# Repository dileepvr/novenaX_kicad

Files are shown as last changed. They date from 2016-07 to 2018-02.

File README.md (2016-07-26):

These are kicad schematics and design files for PCBs used in the
Novena-X project, which aims to build a laptop around the Novena
motherboard released by Kosagi. These design files are being released
(as of this writing on the 30th of April, 2016) under the CERN Open
Hardware License v1.2 (see file LICENSE.txt for text of the license).
All future versions of the CERN Open Hardware License automatically
apply.

For more information about the Novena motherboard, visit: http://www.kosagi.com/w/index.php?title=Novena_Main_Page

For more information about Project Novena-X, visit: http://rightshift.info and refer to the posts titled "Project Novena-X"

The PCB is split into three circuits. One of them is meant to
interface between the Novena front-panel FFC cable and a Dell 0WX4JF
backlit keyboard. It also consists of LEDs driven by six pins from the
FPGA onboard the Novena, as well as buttons for power, reset, and
bluetooth association. The board houses an ATMEGA32u4 microcontroller.

A second circuit merely hosts a pushbutton meant to detect when the case is open/closed.

The third circuit communicates through specific pins on Novena's LVDS
panel FFC cable, and houses two ATMEGA32u4 microcontrollers, as well
as a USB hub (TUSB2046BVFR). This circuit interfaces with an
NHD-044DAZ-FL-YBW 40x4 character LCD screen from New Haven displays,
an e-ink panel arduino shield called ePaper v2 by Seeedstudio, a USB
camera, an nRF24L01+ radio module from Nordic, as well as i2c chips
such as the BME280 weather monitor, the ATAE5132A encrypted EEPROM,
and a AT97SC3205T TPM chip from Atmel.

- Dileep V. Reddy

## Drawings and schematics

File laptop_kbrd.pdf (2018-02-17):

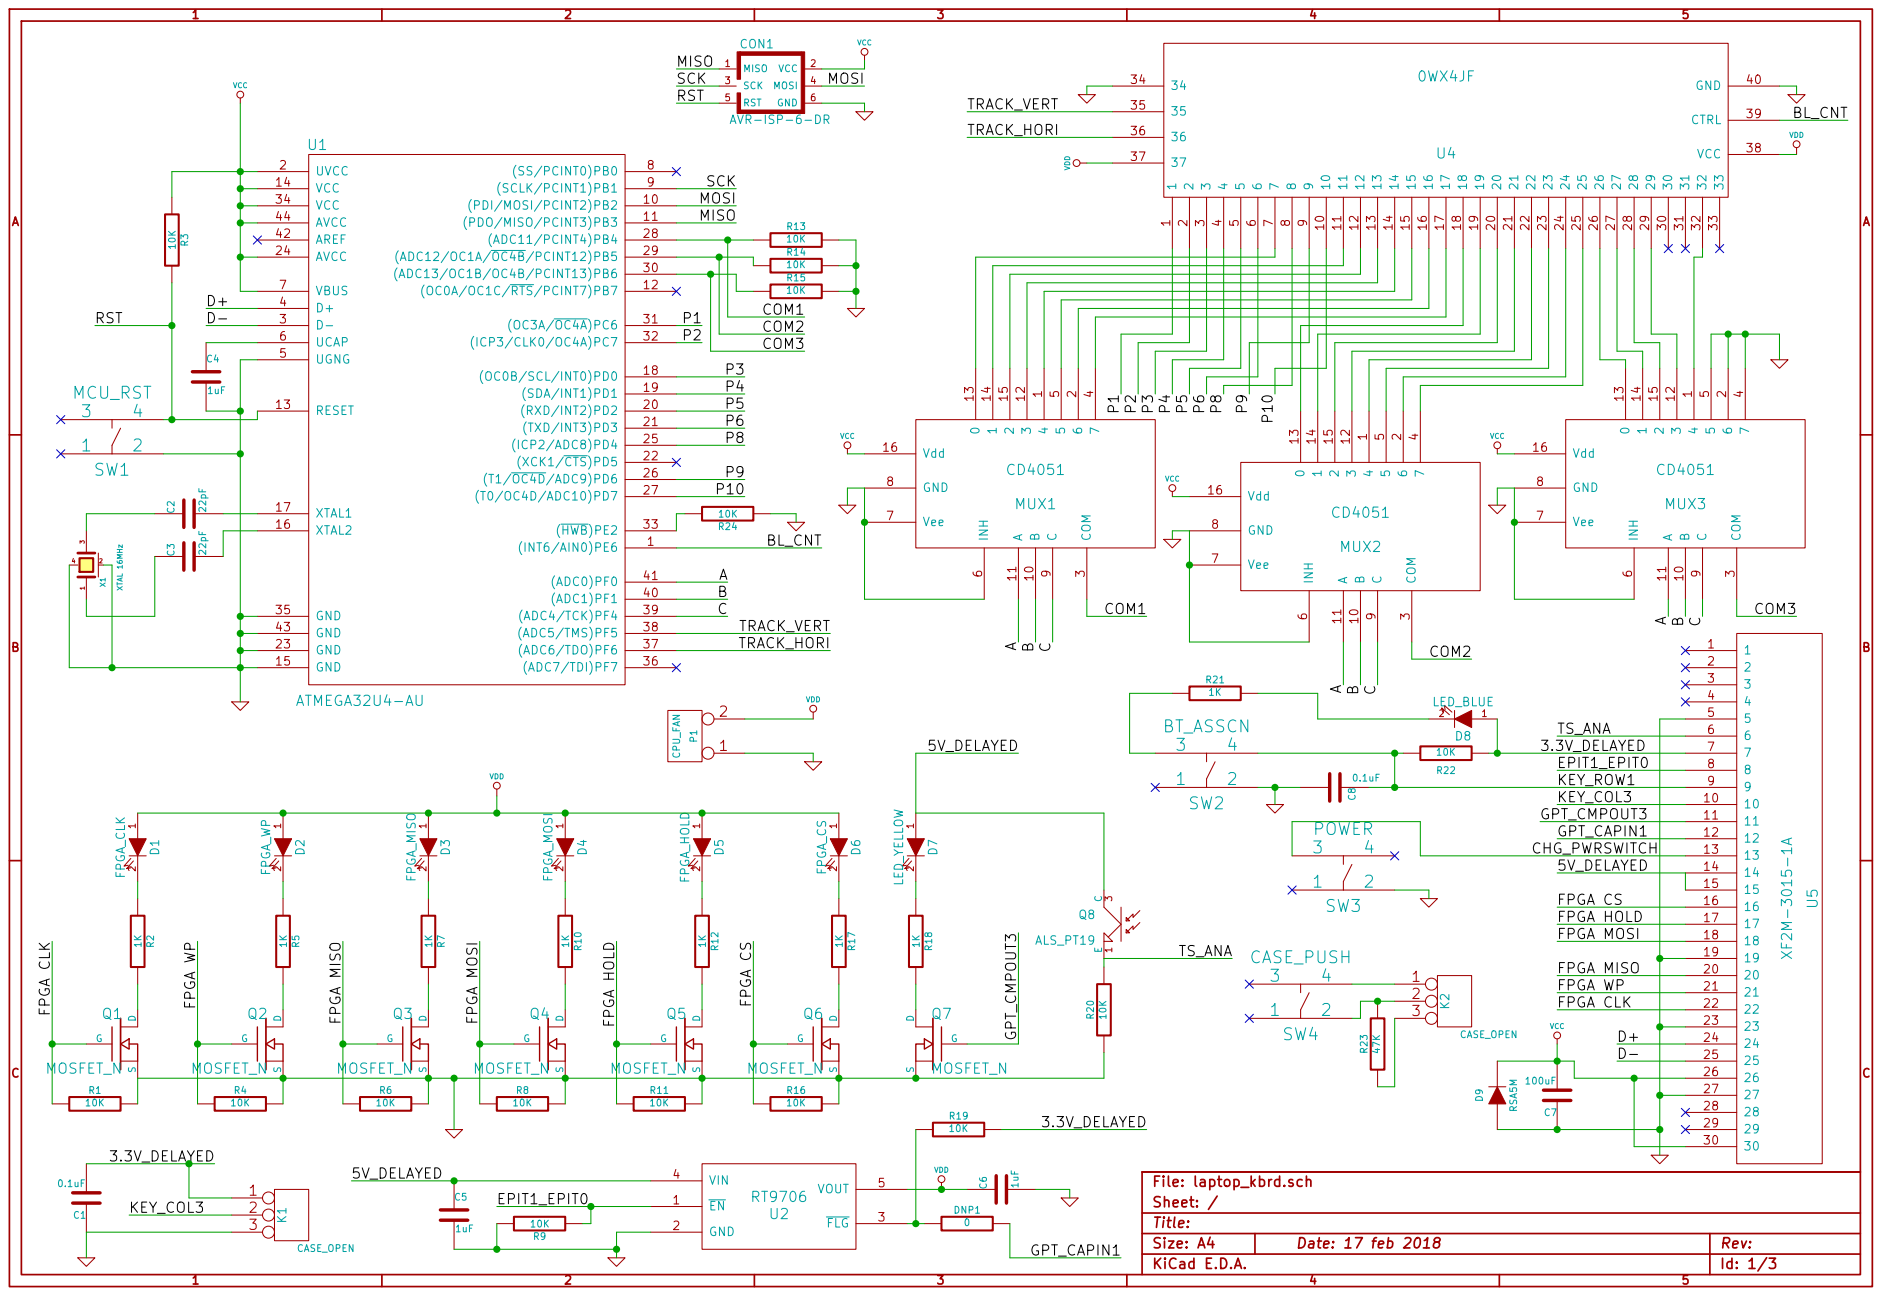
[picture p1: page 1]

EPIT1_EPIT0 | | | | 8
KEY_ROW1 | | 9
KEY_COL3 | | | | 10 10

FPGA HOLD | | 17 17
FPGA MOSI | 18 18

FPGA WP | 21 21
FPGA CLK | | 22 22

Id: 1/3 Title: File: laptop_kbrd.sch
Sheet: /

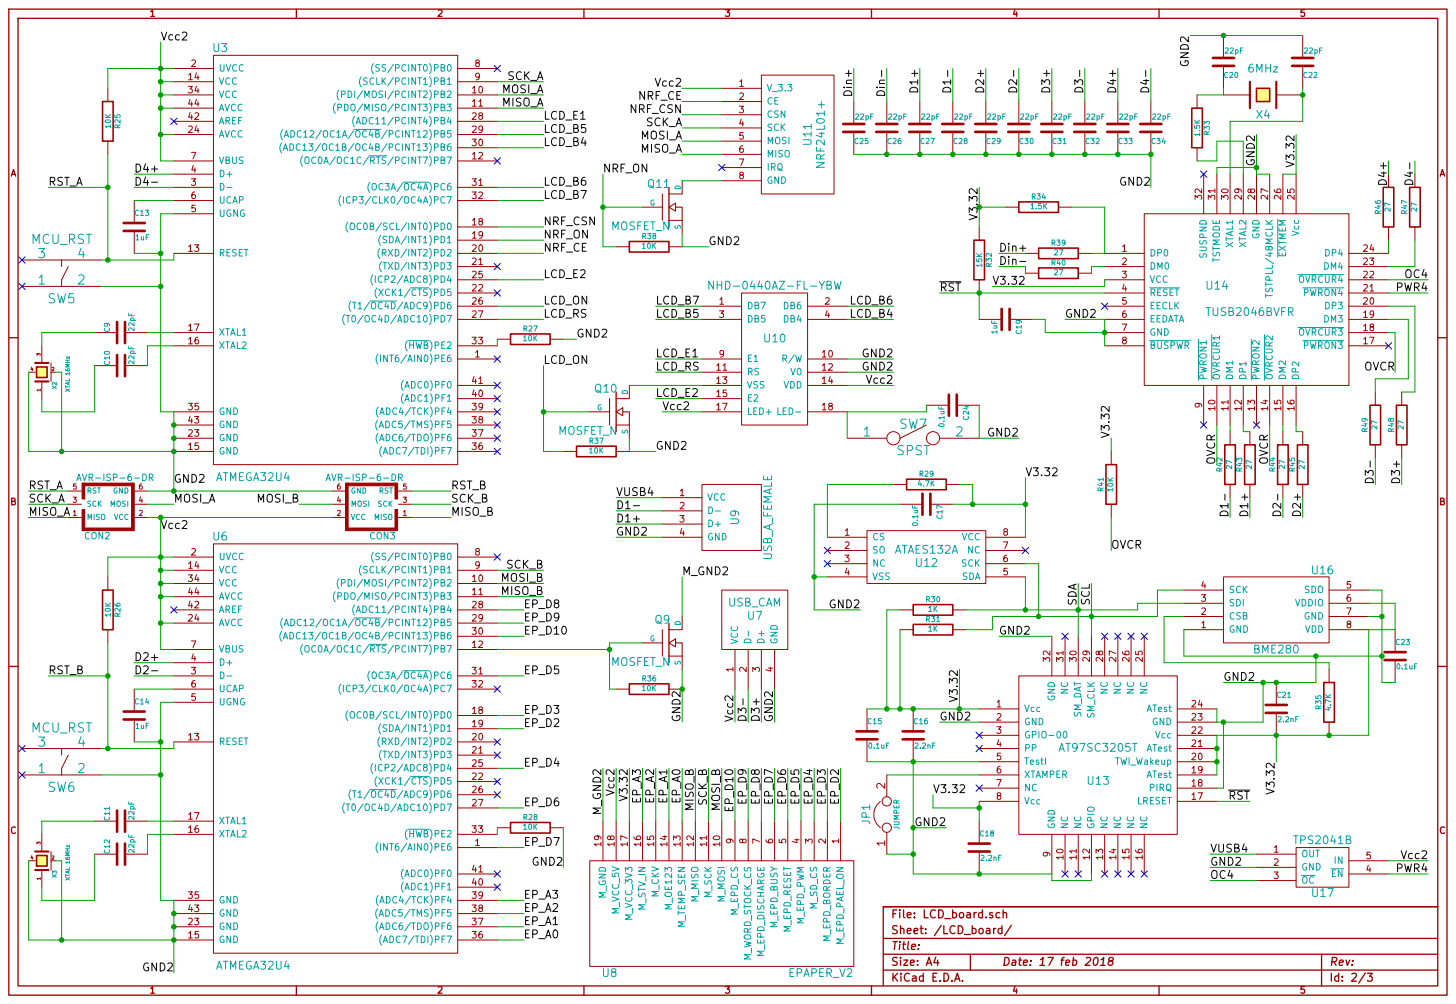
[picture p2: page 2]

9 OVRCUR1 10 DP3 20 XTAL1 30 DM1 11 PWRON4 21 TSTMODE 31 DP1 12 OVRCUR4 22 SUSPND 32 PWRON2 13 DM4 23 OVRCUR2 14 DP4 24 DM2 15 Vcc 25 DP2 16 EXTMEM 26 PWRON3 17 TSTPLL/48MCLK 27 OVRCUR3 18 GND 28 DM3 19 XTAL2 29 U14 TUSB2046BVFR

Id: 2/3 Title: File: LCD_board.sch
Sheet: /LCD_board/

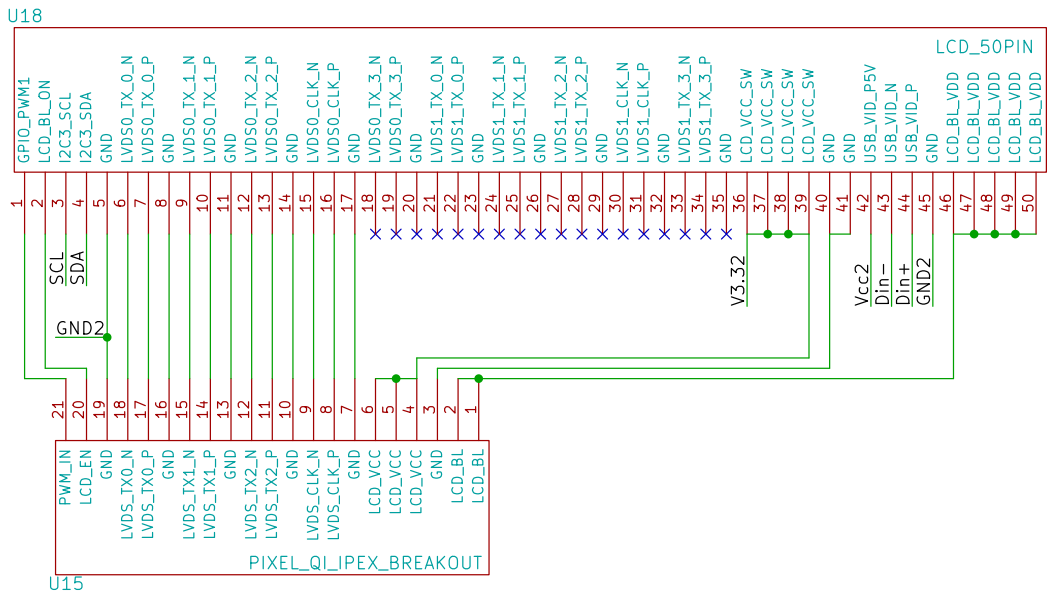
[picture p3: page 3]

9 GND 10 LCD_EN 20 LVDS_TX2_P 11 PWM_IN 21 LVDS_TX2_N 12 GND 13 LVDS_TX1_P 14 LVDS_TX1_N 15 GND 16 LVDS_TX0_P 17 LVDS_TX0_N 18 GND 19 U15 PIXEL_QI_IPEX_BREAKOUT GPIO_PWM1

9 LVDS0_TX_1_P 10 GND 20 LVDS1_CLK_N 30 GND 40 LCD_BL_VDD 50 GND 11 LVDS1_TX_0_N 21 LVDS1_CLK_P 31 GND 41 LVDS0_TX_2_N 12 LVDS1_TX_0_P 22 GND 32 USB_VID_P5V 42 LVDS0_TX_2_P 13 GND 23 LVDS1_TX_3_N 33 USB_VID_N 43 GND 14 LVDS1_TX_1_N 24 LVDS1_TX_3_P 34 USB_VID_P 44 LVDS0_CLK_N 15 LVDS1_TX_1_P 25 GND 35 GND 45 LVDS0_CLK_P 16 GND 26 LCD_VCC_SW 36 LCD_BL_VDD 46 GND 17 LVDS1_TX_2_N 27 LCD_VCC_SW 37 LCD_BL_VDD 47 LVDS0_TX_3_N 18 LVDS1_TX_2_P 28 LCD_VCC_SW 38 LCD_BL_VDD 48 LVDS0_TX_3_P 19 GND 29 LCD_VCC_SW 39 LCD_BL_VDD 49

Id: 3/3 Title: File: LVDS_FFCcable.sch

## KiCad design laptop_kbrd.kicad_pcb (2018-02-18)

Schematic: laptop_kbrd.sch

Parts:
C1, C8: 0.1uF
C2, C3: 22pF
C4, C5, C6: 1uF
C7: 100uF
CON1: AVR-ISP-6-DR; AVR-ISP-6
D1: FPGA_CLK
D2: FPGA_WP
D3: FPGA_MISO
D4: FPGA_MOSI
D5: FPGA_HOLD
D6: FPGA_CS
D7: LED_YELLOW
D8: LED_BLUE
D9: RSA5M
DNP1: 0
K1, K2: CASE_OPEN
MUX1, MUX2, MUX3: CD4051
P1: CPU_FAN
Q1, Q2, Q3, Q4, Q5, Q6, Q7: MOSFET_N
Q8: ALS_PT19
R1, R3, R4, R6, R8, R9, R11, R13, R14, R15, R16, R19, R20, R22, R24: 10K
R2, R5, R7, R10, R12, R17, R18, R21: 1K
R23: 47K
SW1: MCU_RST
SW2: BT_ASSCN
SW3: POWER
SW4: CASE_PUSH
U1: ATMEGA32U4-AU
U2: RT9706
U4: 0WX4JF
U5: XF2M-3015-1A
X1: XTAL 16MHz

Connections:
/3.3V_DELAYED: C1.2, D8.1 (A), K1.1, R19.2, R22.2, U5.7
/5V_DELAYED: C5.1, D7.1 (A), Q8.3 (C), U2.4 (VIN), U5.14, U5.15
/A: MUX1.11 (A), MUX2.11 (A), MUX3.11 (A), U1.41
/B: MUX1.10 (B), MUX2.10 (B), MUX3.10 (B), U1.40
/BL_CNT: U1.1, U4.39 (CTRL)
/C: MUX1.9 (C), MUX2.9 (C), MUX3.9 (C), U1.39
/CHG_PWRSWITCH: SW3.3, U5.13
/COM1: MUX1.3 (COM), R13.1, U1.28
/COM2: MUX2.3 (COM), R14.1, U1.29
/COM3: MUX3.3 (COM), R15.1, U1.30
/D+: U1.4, U5.24
/D-: U1.3, U5.25
/EPIT1_EPIT0: R9.1, U2.1 (~EN), U5.8
/FPGA CLK: Q1.G, R1.1, U5.22
/FPGA CS: Q6.G, R16.1, U5.16
/FPGA HOLD: Q5.G, R11.1, U5.17
/FPGA MISO: Q3.G, R6.1, U5.20
/FPGA MOSI: Q4.G, R8.1, U5.18
/FPGA WP: Q2.G, R4.1, U5.21
/GPT_CAPIN1: DNP1.2, U5.12
/GPT_CMPOUT3: Q7.G, U5.11
/KEY_COL3: K1.2 (PM), U5.10
/KEY_ROW1: C8.1, R22.1, SW2.4, U5.9
/MISO: CON1.1 (MISO), U1.11
/MOSI: CON1.4 (MOSI), U1.10
/P1: U1.31, U4.1
/P2: U1.32, U4.2
/P3: U1.18, U4.3
/P4: U1.19, U4.4
/P5: U1.20, U4.5
/P6: U1.21, U4.6
/P8: U1.25, U4.8
/P9: U1.26, U4.9
/P10: U1.27, U4.10
/RST: CON1.5 (RST), R3.2, SW1.4, U1.13
/SCK: CON1.3 (SCK), U1.9
/TRACK_HORI: U1.37, U4.36
/TRACK_VERT: U1.38, U4.35
/TS_ANA: Q8.1 (E), R20.2, U5.6
GND: C1.1, C4.2, C5.2, C6.2, C7.1, C8.2, CON1.6 (GND), D9.1 (A), K1.3, MUX1.6 (INH), MUX1.7 (Vee), MUX1.8 (GND), MUX2.6 (INH), MUX2.7 (Vee), MUX2.8 (GND), MUX3.2 (6), MUX3.4 (7), MUX3.5, MUX3.6 (INH), MUX3.7 (Vee), MUX3.8 (GND), P1.1, Q1.S, Q2.S, Q3.S, Q4.S, Q5.S, Q6.S, Q7.S, R1.2, R4.2, R6.2, R8.2, R9.2, R11.2, R13.2, R14.2, R15.2, R16.2, R20.1, R24.1, SW1.2, SW2.2, SW3.2, U1.5, U1.15, U1.23, U1.35, U1.43, U2.2 (GND), U4.34, U4.40 (GND), U5.5, U5.19, U5.23, U5.27, X1.2 (case), X1.4
unnamed: MUX3.1 (4), U4.32
unnamed: C2.2, U1.17
unnamed: C3.2, U1.16
unnamed: C2.1, X1.3
unnamed: C3.1, X1.1
unnamed: MUX2.12 (3), U4.21
unnamed: MUX2.1 (4), U4.22
unnamed: MUX2.5, U4.23
unnamed: MUX2.2 (6), U4.24
unnamed: MUX2.4 (7), U4.25
unnamed: MUX3.13 (0), U4.26
unnamed: MUX3.14 (1), U4.27
unnamed: MUX3.15 (2), U4.28
unnamed: MUX3.12 (3), U4.29
unnamed: MUX1.15 (2), U4.12
unnamed: MUX1.12 (3), U4.13
unnamed: MUX1.1 (4), U4.14
unnamed: MUX1.5, U4.15
unnamed: MUX1.2 (6), U4.16
unnamed: MUX1.4 (7), U4.17
unnamed: MUX2.13 (0), U4.18
unnamed: MUX2.14 (1), U4.19
unnamed: MUX2.15 (2), U4.20
unnamed: C4.1, U1.6
unnamed: DNP1.1, R19.1, U2.3 (~FLG)
unnamed: R24.2, U1.33
unnamed: K2.3, R23.1
unnamed: K2.1, SW4.4
unnamed: K2.2 (PM), R23.2, SW4.2
unnamed: D1.2 (K), R2.1
unnamed: Q1.D, R2.2
unnamed: D8.2 (K), R21.2
unnamed: R21.1, SW2.3
unnamed: D2.2 (K), R5.1
unnamed: Q2.D, R5.2
unnamed: Q7.D, R18.2
unnamed: D5.2 (K), R12.1
unnamed: D3.2 (K), R7.1
unnamed: Q3.D, R7.2
unnamed: D4.2 (K), R10.1
unnamed: Q4.D, R10.2
unnamed: Q5.D, R12.2
unnamed: D6.2 (K), R17.1
unnamed: Q6.D, R17.2
unnamed: D7.2 (K), R18.1
unnamed: MUX1.13 (0), U4.7
unnamed: MUX1.14 (1), U4.11
VCC: C7.2, CON1.2 (VCC), D9.2 (K), MUX1.16 (Vdd), MUX2.16 (Vdd), MUX3.16 (Vdd), R3.1, U1.2, U1.7, U1.14, U1.24, U1.34, U1.44, U5.26, U5.30
VDD: C6.1, D1.1 (A), D2.1 (A), D3.1 (A), D4.1 (A), D5.1 (A), D6.1 (A), P1.2 (PM), U2.5 (VOUT), U4.37, U4.38 (VCC)

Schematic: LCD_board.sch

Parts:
C9, C10, C11, C12, C20, C22, C25, C26, C27, C28, C29, C30, C31, C32, C33, C34: 22pF
C13, C14, C19: 1uF
C15, C17, C23, C24: 0.1uF
C16, C18, C21: 2.2nF
CON2, CON3: AVR-ISP-6-DR; AVR-ISP-6
JP1: JUMPER
Q9, Q10, Q11: MOSFET_N
R25, R26, R27, R28, R36, R37, R38, R41: 10K
R29, R35: 4.7K
R30, R31: 1K
R32: 15K
R33, R34: 1.5K
R39, R40, R42, R43, R44, R45, R46, R47, R48, R49: 27
SW5, SW6: MCU_RST
SW7: SPST
U3, U6: ATMEGA32U4
U7: USB_CAM
U8: EPAPER_V2
U9: USB_A_FEMALE
U10: NHD-0440AZ-FL-YBW
U11: NRF24L01+
U12: ATAES132A
U13: AT97SC3205T
U14: TUSB2046BVFR
U16: BME280
U17: TPS2041B
X2, X3: XTAL 16MHz
X4: 6MHz

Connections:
/LCD_board/D1+: C27.2, R43.2, U9.3 (D+)
/LCD_board/D1-: C28.2, R42.2, U9.2 (D-)
/LCD_board/D2+: C29.2, R45.2, U6.4
/LCD_board/D2-: C30.2, R44.2, U6.3
/LCD_board/D4+: C33.2, R46.1, U3.4
/LCD_board/D4-: C34.2, R47.1, U3.3
/LCD_board/Din+: C25.2, R39.2; also elsewhere on the board
/LCD_board/Din-: C26.2, R40.2; also elsewhere on the board
/LCD_board/EP_A0: U6.36, U8.13 (M_TEMP_SEN)
/LCD_board/EP_A1: U6.37, U8.14 (M_OE123)
/LCD_board/EP_A2: U6.38, U8.15 (M_CKV)
/LCD_board/EP_A3: U6.39, U8.16 (M_STV_IN)
/LCD_board/EP_D2: U6.19, U8.1 (M_EPD_PAEL_ON)
/LCD_board/EP_D3: U6.18, U8.2 (M_EPD_BORDER)
/LCD_board/EP_D4: U6.25, U8.3 (M_SD_CS)
/LCD_board/EP_D5: U6.31, U8.4 (M_EPD_PWM)
/LCD_board/EP_D6: U6.27, U8.5 (M_EPD_RESET)
/LCD_board/EP_D7: U6.1, U8.6 (M_EPD_BUSY)
/LCD_board/EP_D8: U6.28, U8.7 (M_EPD_DISCHARGE)
/LCD_board/EP_D9: U6.29, U8.8 (M_WORD_STOCK_CS)
/LCD_board/EP_D10: U6.30, U8.9 (M_EPD_CS)
/LCD_board/GND2: C13.2, C14.2, C15.2, C16.2, C17.2, C18.2, C19.1, C20.2, C21.1, C22.2, C23.2, C24.1, C25.1, C26.1, C27.1, C28.1, C29.1, C30.1, C31.1, C32.1, C33.1, C34.1, CON2.6 (GND), CON3.6 (GND), JP1.1, Q9.S, Q10.S, Q11.S, R27.2, R28.2, R36.2, R37.2, R38.2, SW5.2, SW6.2, SW7.2, U3.5, U3.15, U3.23, U3.35, U3.43, U6.5, U6.15, U6.23, U6.35, U6.43, U7.4 (GND), U9.4 (GND), U10.10 (R/W), U10.12 (V0), U12.4 (VSS), U13.2 (GND), U13.5 (TestI), U13.9 (GND), U13.12 (GPIO), U13.18 (PIRQ), U13.23 (GND), U13.24 (ATest), U13.32 (GND), U14.6 (EEDATA), U14.7 (GND), U14.8 (~BUSPWR), U14.27 (TSTPLL/48MCLK), U14.28 (GND), U14.31 (TSTMODE), U16.1 (GND), U16.5 (SDO), U16.7 (GND), U17.2 (GND), X2.2 (case), X2.4, X3.2 (case), X3.4; also elsewhere on the board
/LCD_board/LCD_B4: U3.30, U10.4 (DB4)
/LCD_board/LCD_B5: U3.29, U10.3 (DB5)
/LCD_board/LCD_B6: U3.31, U10.2 (DB6)
/LCD_board/LCD_B7: U3.32, U10.1 (DB7)
/LCD_board/LCD_E1: U3.28, U10.9 (E1)
/LCD_board/LCD_E2: U3.25, U10.15 (E2)
/LCD_board/LCD_ON: Q10.G, R37.1, U3.26
/LCD_board/LCD_RS: U3.27, U10.11 (RS)
/LCD_board/MISO_A: CON2.1 (MISO), U3.11, U11.6 (MISO)
/LCD_board/MISO_B: CON3.1 (MISO), U6.11, U8.12 (M_MISO)
/LCD_board/MOSI_A: CON2.4 (MOSI), U3.10, U11.5 (MOSI)
/LCD_board/MOSI_B: CON3.4 (MOSI), U6.10, U8.10 (M_MOSI)
/LCD_board/M_GND2: Q9.D, U8.19 (M_GND)
/LCD_board/NRF_CE: U3.20, U11.2 (CE)
/LCD_board/NRF_CSN: U3.18, U11.3 (CSN)
/LCD_board/NRF_ON: Q11.G, R38.1, U3.19
/LCD_board/OC4: U14.22 (~OVRCUR4), U17.3 (~OC)
/LCD_board/OVCR: R41.1, U14.10 (~OVRCUR1), U14.14 (~OVRCUR2), U14.18 (~OVRCUR3)
/LCD_board/PWR4: U14.21 (~PWRON4), U17.4 (~EN)
/LCD_board/RST_A: CON2.5 (RST), R25.2, SW5.4, U3.13
/LCD_board/RST_B: CON3.5 (RST), R26.2, SW6.4, U6.13
/LCD_board/SCK_A: CON2.3 (SCK), U3.9, U11.4 (SCK)
/LCD_board/SCK_B: CON3.3 (SCK), U6.9, U8.11 (M_SCK)
/LCD_board/SCL: R31.2, U12.6 (SCK), U13.29 (SM_CLK), U16.4 (SCK); also elsewhere on the board
/LCD_board/SDA: R30.2, U12.5 (SDA), U13.30 (SM_DAT), U16.3 (SDI); also elsewhere on the board
/LCD_board/V3.32: C15.1, C16.1, C17.1, C18.1, C21.2, C23.1, R29.2, R30.1, R31.1, R32.2, R34.2, R35.1, R41.2, U8.17 (M_VCC_3V3), U12.8 (VCC), U13.1 (Vcc), U13.8 (Vcc), U13.19 (ATest), U13.20 (TWI_Wakeup), U13.21 (ATest), U13.22 (Vcc), U14.3 (VCC), U14.25 (Vcc), U14.26 (~EXTMEM), U16.6 (VDDIO), U16.8 (VDD); also elsewhere on the board
/LCD_board/VUSB4: U9.1 (VCC), U17.1 (OUT)
/LCD_board/Vcc2: CON2.2 (VCC), CON3.2 (VCC), R25.1, R26.1, U3.2, U3.7, U3.14, U3.24, U3.34, U3.44, U6.2, U6.7, U6.14, U6.24, U6.34, U6.44, U7.1 (VCC), U8.18 (M_VCC_5V), U10.14 (VDD), U10.17 (LED+), U11.1 (V_3.3), U17.5 (IN); also elsewhere on the board
/LCD_board/~RST: C19.2, R32.1, U13.17 (LRESET), U14.4 (~RESET)
unnamed: JP1.2, U13.6 (XTAMPER)
unnamed: R33.1, U14.29 (XTAL2)
unnamed: Q11.D, U11.8 (GND)
unnamed: Q10.D, U10.13 (VSS)
unnamed: Q9.G, R36.1, U6.12
unnamed: R35.2, U16.2 (CSB)
unnamed: R29.1, U12.1 (CS)
unnamed: C13.1, U3.6
unnamed: C9.1, X2.3
unnamed: C10.1, X2.1
unnamed: C10.2, U3.16
unnamed: C20.1, R33.2, X4.1
unnamed: R27.1, U3.33
unnamed: R28.1, U6.33
unnamed: R46.2, U14.24 (DP4)
unnamed: R47.2, U14.23 (DM4)
unnamed: R44.1, U14.15 (DM2)
unnamed: R43.1, U14.12 (DP1)
unnamed: R42.1, U14.11 (DM1)
unnamed: R45.1, U14.16 (DP2)
unnamed: R34.1, R39.1, U14.1 (DP0)
unnamed: R40.1, U14.2 (DM0)
unnamed: C9.2, U3.17
unnamed: C24.2, SW7.1, U10.18 (LED-)
unnamed: C11.1, X3.3
unnamed: C12.1, X3.1
unnamed: C12.2, U6.16
unnamed: C11.2, U6.17
unnamed: C14.1, U6.6
unnamed: C22.1, U14.30 (XTAL1), X4.2

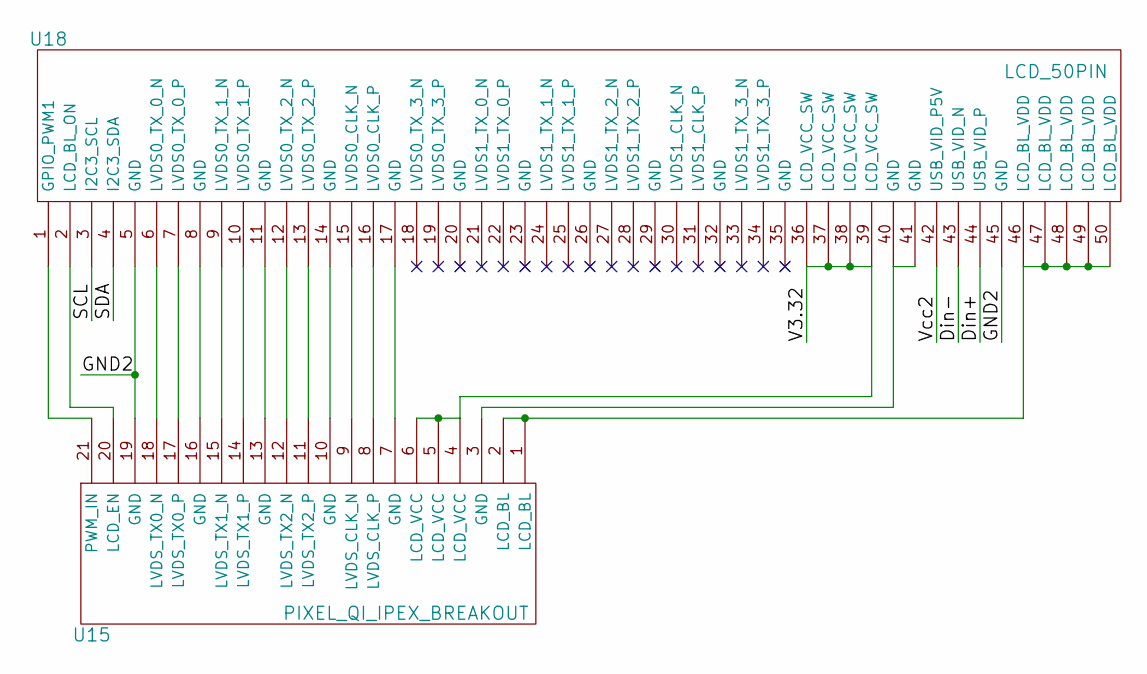
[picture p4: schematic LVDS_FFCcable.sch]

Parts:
U15: PIXEL_QI_IPEX_BREAKOUT
U18: LCD_50PIN

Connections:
/LCD_board/Din+: U18.44 (USB_VID_P); also elsewhere on the board
/LCD_board/Din-: U18.43 (USB_VID_N); also elsewhere on the board
/LCD_board/GND2: U15.19 (GND), U18.5 (GND), U18.45 (GND); also elsewhere on the board
/LCD_board/SCL: U18.3 (I2C3_SCL); also elsewhere on the board
/LCD_board/SDA: U18.4 (I2C3_SDA); also elsewhere on the board
/LCD_board/V3.32: U15.4 (LCD_VCC), U15.5 (LCD_VCC), U15.6 (LCD_VCC), U18.36 (LCD_VCC_SW), U18.37 (LCD_VCC_SW), U18.38 (LCD_VCC_SW), U18.39 (LCD_VCC_SW); also elsewhere on the board
/LCD_board/Vcc2: U18.42 (USB_VID_P5V); also elsewhere on the board
unnamed: U15.10 (GND), U18.14 (GND)
unnamed: U15.7 (GND), U18.17 (GND)
unnamed: U15.8 (LVDS_CLK_P), U18.16 (LVDS0_CLK_P)
unnamed: U15.9 (LVDS_CLK_N), U18.15 (LVDS0_CLK_N)
unnamed: U15.11 (LVDS_TX2_P), U18.13 (LVDS0_TX_2_P)
unnamed: U15.12 (LVDS_TX2_N), U18.12 (LVDS0_TX_2_N)
unnamed: U15.13 (GND), U18.11 (GND)
unnamed: U15.14 (LVDS_TX1_P), U18.10 (LVDS0_TX_1_P)
unnamed: U15.15 (LVDS_TX1_N), U18.9 (LVDS0_TX_1_N)
unnamed: U15.16 (GND), U18.8 (GND)
unnamed: U15.20 (LCD_EN), U18.2 (LCD_BL_ON)
unnamed: U15.3 (GND), U18.40 (GND), U18.41 (GND)
unnamed: U15.21 (PWM_IN), U18.1 (GPIO_PWM1)
unnamed: U15.17 (LVDS_TX0_P), U18.7 (LVDS0_TX_0_P)
unnamed: U15.18 (LVDS_TX0_N), U18.6 (LVDS0_TX_0_N)
unnamed: U15.1 (LCD_BL), U15.2 (LCD_BL), U18.46 (LCD_BL_VDD), U18.47 (LCD_BL_VDD), U18.48 (LCD_BL_VDD), U18.49 (LCD_BL_VDD), U18.50 (LCD_BL_VDD)

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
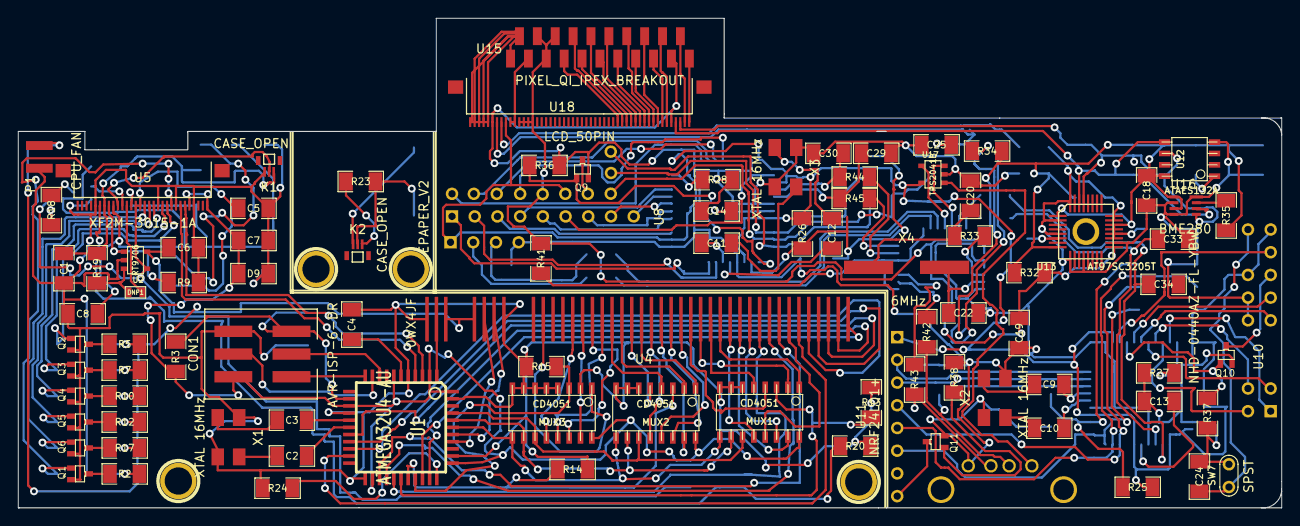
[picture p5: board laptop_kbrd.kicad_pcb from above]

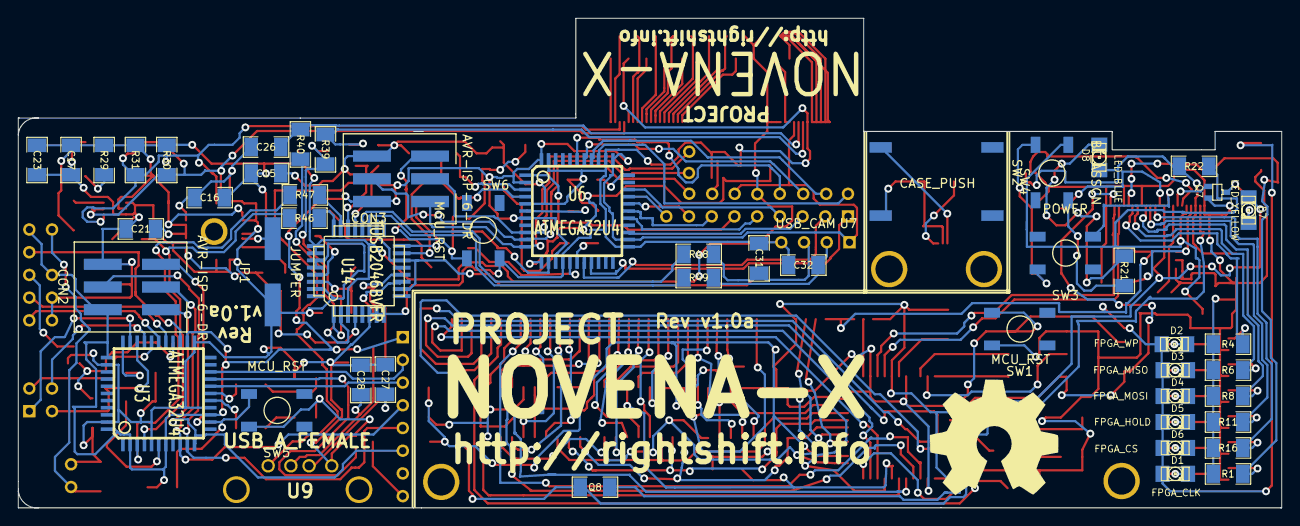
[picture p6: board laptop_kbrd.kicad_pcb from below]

Board: 2 copper layers, 141.3 x 54.8 mm, 143 parts (51 on the bottom side), 190 nets.

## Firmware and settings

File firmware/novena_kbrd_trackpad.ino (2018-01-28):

#include "Keyboard.h"
#include "Mouse.h"
#include <avr/power.h>
#include <avr/sleep.h>
#include <ps2.h>
#define PS2_DATA 11
#define PS2_CLK 18

#include "keymaps.h"

byte mstat1;
byte mstat2;
byte mxy;
byte mx;                  
byte my;      
byte mz;               
int msval[2], msval_old[2];
int repeatCnt, mflag;

PS2 moose(PS2_CLK, PS2_DATA); 

volatile bool poll = true; // For interrupt-based waking using Timer1

bool kbrd[9][21];
bool keychange[9][21];

bool backlight = false;

const int mouse_speed = 40;

// row pins { PC6, PC7, PD0, PD1, PD2, PD3, PD4, PD6, PD7 }
const int row_pins[] = {5, 13, 3, 2, 0, 1, 4, 12, 6};
// MUX read pins { PB4, PB5, PB6 }
const int com_pins[] = {8, 9, 10};
// { PF0, PF1, PF4 }
const int addr_pins[] = {A5, A4, A3};
// keyboard backlight control (active high) - PE6
const int bklight_cnt = 7;
// trackpoint analog signals - PF5; PF6
const int trac_vert = A2; const int trac_hori = A1;

void ms_read()
{
  moose.write(0xeb);
  moose.read();
  mstat1 = moose.read();
  mxy = moose.read();
  mz = moose.read();
  mstat2 = moose.read();
  mx = moose.read();
  my = moose.read();
  msval[0] = (((mstat2 & 0x10) << 8) | ((mxy & 0x0F) << 8) | mx );
  msval[1] = (((mstat2 & 0x20) << 7) | ((mxy & 0xF0) << 4) | my );
  msval[2] = int(mz);
}

// Interrupt service routine gets executed on wake-up
//ISR(TIMER1_OVF_vect) {
ISR(TIMER1_COMPA_vect) {

  if (!poll) {
    poll = true; //!poll;
  }

}


// Goodnight Cinderella
void enterSleep(void) {

  set_sleep_mode(SLEEP_MODE_IDLE);

  sleep_enable();

  sleep_mode();

  sleep_disable();

}

void setup() {

  int i, j;

  for (i = 0; i < 9; i++) {
    pinMode(row_pins[i], OUTPUT); digitalWrite(row_pins[i], LOW);
    for (j = 0; j < 21; j++) {
      kbrd[i][j] = false;
      keychange[i][j] = false;
    }
  }

  for (i = 0; i < 3; i++) {
    pinMode(com_pins[i], INPUT); digitalWrite(com_pins[i], LOW);
    pinMode(addr_pins[i], OUTPUT);
  }

  pinMode(bklight_cnt, OUTPUT);

  digitalWrite(bklight_cnt, HIGH); delay(250); digitalWrite(bklight_cnt, LOW); delay(250);
  digitalWrite(bklight_cnt, HIGH); delay(250); digitalWrite(bklight_cnt, LOW);

  moose.write(0xff); moose.read(); moose.read(); moose.read(); 
  moose.write(0xf0); moose.read(); 
  delayMicroseconds(100);
  moose.write(0xe8); moose.read(); 
  moose.write(0x03); moose.read(); 
  moose.write(0xe8); moose.read(); 
  moose.write(0x00); moose.read();  
  moose.write(0xe8); moose.read();  
  moose.write(0x01); moose.read(); 
  moose.write(0xe8); moose.read(); 
  moose.write(0x00); moose.read(); 
  moose.write(0xf3); moose.read(); 
  moose.write(0x14); moose.read(); 

  // Configure the timer.
  cli(); // disable global interrupts
  // Normal timer operation.
  TCCR1A = 0x00;

  // Clear the timer counter register.
  TCNT1 = 0x0000;

  // Configure the prescaler for 1:2, giving us a
  // timeout of 8 milliseconds.
  TCCR1B = 0x02;

  // Set compare register to half of 65536
  // so we get interrupt every 4 milliseconds
  OCR1A = 32768;

  // Enable the timer overlow interrupt.
  //  TIMSK1 = 0x01;

  // Enable CTC mode
  TCCR1B |= (1 << WGM12);  
  TIMSK1 |= (1 << OCIE1A);

  // power down unused parts of the chip
  power_timer0_disable();
  power_timer2_disable();
  power_twi_disable();

  Keyboard.begin();
  Mouse.begin();
  sei(); // enable global interrupts

}

void loop() {

  if (poll) { // Check if interrupt has tripped
    poll = false; // !poll;

    // Handle keyboard
    if (read_kbrd()) {
      if ((kbrd[3][1]) || (keychange[5][19] && kbrd[5][19]) || (keychange[3][19] && kbrd[3][19]) || (keychange[2][19] && kbrd[2][19])) {
        // Fn-key depressed or LOCK-1 or LOCK-2 or LOCK-3
        special_tasks();
      } else {
        transmit_keys();
      }
    }

    // Handle trackpad
    power_timer0_enable(); // PS/2 library uses delayMicroseconds() function, uses timer0
    ms_read();
    if (msval[0] > 0 and msval[2] > 10)
      { repeatCnt++; }
    else
    { repeatCnt = 0; mflag = 0; }
    if (repeatCnt > 2)
      {
        if (mflag == 1) {
          Mouse.move((msval[0]-msval_old[0])/5,(msval_old[1]-msval[1])/5);      
        } else if (mflag == 2) {
          Mouse.move(0,0,(msval[1]-msval_old[1])/20);
          mflag++;
        } else if (mflag > 2 && mflag < 5) { // Slowing the scroll rate down
          mflag++;
        } else if (mflag == 5) {
        mflag = 2;
      }
    
    if (mflag == 0) {
      if( msval[0] > 5500 ) { mflag = 2; } // Scroll mode
      else { mflag = 1; } // mouse move mode
    }
    msval_old[0] = msval[0]; msval_old[1] = msval[1];  
  }
  power_timer0_disable();
    
    //handle_trackpoint(); // my trackpoint didn't seem to work
    enterSleep();
  }

}


void handle_trackpoint() {

  Mouse.move(map(analogRead(trac_hori),0,1023,(-1)*mouse_speed,mouse_speed), map(analogRead(trac_vert),0,1023,(-1)*mouse_speed,mouse_speed));

}

bool read_kbrd() {

  bool event = false;

  PORTC |= (1 << PC6); event |= scan_row(0); PORTC &= ~(1 << PC6);
  PORTC |= (1 << PC7); event |= scan_row(1); PORTC &= ~(1 << PC7);
  PORTD |= (1 << PD0); event |= scan_row(2); PORTD &= ~(1 << PD0);
  PORTD |= (1 << PD1); event |= scan_row(3); PORTD &= ~(1 << PD1);
  PORTD |= (1 << PD2); event |= scan_row(4); PORTD &= ~(1 << PD2);
  PORTD |= (1 << PD3); event |= scan_row(5); PORTD &= ~(1 << PD3);
  PORTD |= (1 << PD4); event |= scan_row(6); PORTD &= ~(1 << PD4);
  PORTD |= (1 << PD6); event |= scan_row(7); PORTD &= ~(1 << PD6);
  PORTD |= (1 << PD7); event |= scan_row(8); PORTD &= ~(1 << PD7);

  return event;

}

bool scan_row(int ii) {

  bool haschanged = false;

  PORTF &= ~(1 << PF4); PORTF &= ~(1 << PF1); PORTF &= ~(1 << PF0); // Address 0b000

  if (PINB & (1 << PB4)) {
    if (!kbrd[ii][0]) {
      kbrd[ii][0] = true;
      keychange[ii][0] = true;
      haschanged = true;
    }
  }
  else {
    if (kbrd[ii][0]) {
      kbrd[ii][0] = false;
      keychange[ii][0] = true;
      haschanged = true;
    }
  }
  if (PINB & (1 << PB5)) {
    if (!kbrd[ii][8]) {
      kbrd[ii][8] = true;
      keychange[ii][8] = true;
      haschanged = true;
    }
  }
  else {
    if (kbrd[ii][8]) {
      kbrd[ii][8] = false;
      keychange[ii][8] = true;
      haschanged = true;
    }
  }
  if (PINB & (1 << PB6)) {
    if (!kbrd[ii][16]) {
      kbrd[ii][16] = true;
      keychange[ii][16] = true;
      haschanged = true;
    }
  }
  else {
    if (kbrd[ii][16]) {
      kbrd[ii][16] = false;
      keychange[ii][16] = true;
      haschanged = true;
    }
  }

  PORTF |= (1 << PF0); // Address 0b001

  if (PINB & (1 << PB4)) {
    if (!kbrd[ii][1]) {
      kbrd[ii][1] = true;
      keychange[ii][1] = true;
      haschanged = true;
    }
  }
  else {
    if (kbrd[ii][1]) {
      kbrd[ii][1] = false;
      keychange[ii][1] = true;
      haschanged = true;
    }
  }
  if (PINB & (1 << PB5)) {
    if (!kbrd[ii][9]) {
      kbrd[ii][9] = true;
      keychange[ii][9] = true;
      haschanged = true;
    }
  }
  else {
    if (kbrd[ii][9]) {
      kbrd[ii][9] = false;
      keychange[ii][9] = true;
      haschanged = true;
    }
  }
  if (PINB & (1 << PB6)) {
    if (!kbrd[ii][17]) {
      kbrd[ii][17] = true;
      keychange[ii][17] = true;
      haschanged = true;
    }
  }
  else {
    if (kbrd[ii][17]) {
      kbrd[ii][17] = false;
      keychange[ii][17] = true;
      haschanged = true;
    }
  }

  PORTF |= (1 << PF1); PORTF &= ~(1 << PF0); // Address 0b010

  if (PINB & (1 << PB4)) {
    if (!kbrd[ii][2]) {
      kbrd[ii][2] = true;
      keychange[ii][2] = true;
      haschanged = true;
    }
  }
  else {
    if (kbrd[ii][2]) {
      kbrd[ii][2] = false;
      keychange[ii][2] = true;
      haschanged = true;
    }
  }
  if (PINB & (1 << PB5)) {
    if (!kbrd[ii][10]) {
      kbrd[ii][10] = true;
      keychange[ii][10] = true;
      haschanged = true;
    }
  }
  else {
    if (kbrd[ii][10]) {
      kbrd[ii][10] = false;
      keychange[ii][10] = true;
      haschanged = true;
    }
  }
  if (PINB & (1 << PB6)) {
    if (!kbrd[ii][18]) {
      kbrd[ii][18] = true;
      keychange[ii][18] = true;
      haschanged = true;
    }
  }
  else {
    if (kbrd[ii][18]) {
      kbrd[ii][18] = false;
      keychange[ii][18] = true;
      haschanged = true;
    }
  }

  PORTF |= (1 << PF0); // Address 0b011

  if (PINB & (1 << PB4)) {
    if (!kbrd[ii][3]) {
      kbrd[ii][3] = true;
      keychange[ii][3] = true;
      haschanged = true;
    }
  }
  else {
    if (kbrd[ii][3]) {
      kbrd[ii][3] = false;
      keychange[ii][3] = true;
      haschanged = true;
    }
  }
  if (PINB & (1 << PB5)) {
    if (!kbrd[ii][11]) {
      kbrd[ii][11] = true;
      keychange[ii][11] = true;
      haschanged = true;
    }
  }
  else {
    if (kbrd[ii][11]) {
      kbrd[ii][11] = false;
      keychange[ii][11] = true;
      haschanged = true;
    }
  }
  if (PINB & (1 << PB6)) {
    if (!kbrd[ii][19]) {
      kbrd[ii][19] = true;
      keychange[ii][19] = true;
      haschanged = true;
    }
  }
  else {
    if (kbrd[ii][19]) {
      kbrd[ii][19] = false;
      keychange[ii][19] = true;
      haschanged = true;
    }
  }

  PORTF |= (1 << PF4); PORTF &= ~(1 << PF1); PORTF &= ~(1 << PF0); // Address 0b100

  if (PINB & (1 << PB4)) {
    if (!kbrd[ii][4]) {
      kbrd[ii][4] = true;
      keychange[ii][4] = true;
      haschanged = true;
    }
  }
  else {
    if (kbrd[ii][4]) {
      kbrd[ii][4] = false;
      keychange[ii][4] = true;
      haschanged = true;
    }
  }
  if (PINB & (1 << PB5)) {
    if (!kbrd[ii][12]) {
      kbrd[ii][12] = true;
      keychange[ii][12] = true;
      haschanged = true;
    }
  }
  else {
    if (kbrd[ii][12]) {
      kbrd[ii][12] = false;
      keychange[ii][12] = true;
      haschanged = true;
    }
  }
  if (PINB & (1 << PB6)) {
    if (!kbrd[ii][20]) {
      kbrd[ii][20] = true;
      keychange[ii][20] = true;
      haschanged = true;
    }
  }
  else {
    if (kbrd[ii][20]) {
      kbrd[ii][20] = false;
      keychange[ii][20] = true;
      haschanged = true;
    }
  }

  PORTF |= (1 << PF0); // Address 0b101

  if (PINB & (1 << PB4)) {
    if (!kbrd[ii][5]) {
      kbrd[ii][5] = true;
      keychange[ii][5] = true;
      haschanged = true;
    }
  }
  else {
    if (kbrd[ii][5]) {
      kbrd[ii][5] = false;
      keychange[ii][5] = true;
      haschanged = true;
    }
  }
  if (PINB & (1 << PB5)) {
    if (!kbrd[ii][13]) {
      kbrd[ii][13] = true;
      keychange[ii][13] = true;
      haschanged = true;
    }
  }
  else {
    if (kbrd[ii][13]) {
      kbrd[ii][13] = false;
      keychange[ii][13] = true;
      haschanged = true;
    }
  }

  PORTF |= (1 << PF1); PORTF &= ~(1 << PF0); // Address 0b110

  if (PINB & (1 << PB4)) {
    if (!kbrd[ii][6]) {
      kbrd[ii][6] = true;
      keychange[ii][6] = true;
      haschanged = true;
    }
  }
  else {
    if (kbrd[ii][6]) {
      kbrd[ii][6] = false;
      keychange[ii][6] = true;
      haschanged = true;
    }
  }
  if (PINB & (1 << PB5)) {
    if (!kbrd[ii][14]) {
      kbrd[ii][14] = true;
      keychange[ii][14] = true;
      haschanged = true;
    }
  }
  else {
    if (kbrd[ii][14]) {
      kbrd[ii][14] = false;
      keychange[ii][14] = true;
      haschanged = true;
    }
  }

  PORTF |= (1 << PF0); // Address 0b111

  if (PINB & (1 << PB4)) {
    if (!kbrd[ii][7]) {
      kbrd[ii][7] = true;
      keychange[ii][7] = true;
      haschanged = true;
    }
  }
  else {
    if (kbrd[ii][7]) {
      kbrd[ii][7] = false;
      keychange[ii][7] = true;
      haschanged = true;
    }
  }
  if (PINB & (1 << PB5)) {
    if (!kbrd[ii][15]) {
      kbrd[ii][15] = true;
      keychange[ii][15] = true;
      haschanged = true;
    }
  }
  else {
    if (kbrd[ii][15]) {
      kbrd[ii][15] = false;
      keychange[ii][15] = true;
      haschanged = true;
    }
  }

  return haschanged;

}


void special_tasks() {

  if (kbrd[3][1]) { // Fn-key pressed

    if (keychange[1][18] && kbrd[1][18]) { // right-arrow
      backlight = !backlight;
      if (backlight) {
        PORTE |= (1 << PE6);  // turn keyboard backlight on
      }
      else {
        PORTE &= ~(1 << PE6);  // turn keyboard backlight off
      }
    }

    if (keychange[1][16]) {
      if (kbrd[1][16]) {
        Keyboard.press(KEY_MUTE);  // left-arrow
      } else {
        Keyboard.release(KEY_MUTE);
      } keychange[1][16] = false;
    }
    if (keychange[1][17]) {
      if (kbrd[1][17]) {
        Keyboard.press(KEY_VOLUME_DOWN);  // down-arrow
      } else {
        Keyboard.release(KEY_VOLUME_DOWN);
      } keychange[1][17] = false;
    }
    if (keychange[8][16]) {
      if (kbrd[8][16]) {
        Keyboard.press(KEY_VOLUME_UP);  // up-arrow
      } else {
        Keyboard.release(KEY_VOLUME_UP);
      } keychange[8][16] = false;
    }
    if (keychange[5][10]) {
      if (kbrd[5][10]) {
        Keyboard.press(KEY_SYSRQ);  // F10
      } else {
        Keyboard.release(KEY_SYSRQ);
      } keychange[5][10] = false;
    }
    if (keychange[5][17]) {
      if (kbrd[5][17]) {
        Keyboard.press(KEY_PRTSC);  // F11
      } else {
        Keyboard.release(KEY_PRTSC);
      } keychange[5][17] = false;
    }
    if (keychange[5][18]) {
      if (kbrd[5][18]) {
        Keyboard.press(KEY_PAUSE);  // F12
      } else {
        Keyboard.release(KEY_PAUSE);
      } keychange[5][18] = false;
    }
    

// Had to keep the following commented out, as it interfered with the trackpad function
/*    if (keychange[2][11]) {
      if (kbrd[2][11]) {
        Keyboard.press('0');  // m        
      } else {
        Keyboard.release('0');
      } keychange[2][11] = false;
    }
    if (keychange[2][14]) {    
      if (kbrd[2][14]) {
        Keyboard.press('.');  // .
      } else {
        Keyboard.release('.');
      } keychange[2][14] = false;
    }
    if (keychange[1][13]) {
      if (kbrd[1][13]) {
        Keyboard.press('+');  // /
      } else {
        Keyboard.release('+');
      } keychange[1][13] = false;
    }
    if (keychange[3][11]) {
      if (kbrd[3][11]) {
        Keyboard.press('1');  // j
      } else {
        Keyboard.release('1');
      } keychange[3][11] = false;
    }
    if (keychange[3][12]) {
      if (kbrd[3][12]) {
        Keyboard.press('2');  // k
      } else {
        Keyboard.release('2');
      } keychange[3][12] = false;
    }
    if (keychange[3][14]) {
      if (kbrd[3][14]) {
        Keyboard.press('3');  // l
      } else {
        Keyboard.release('3');
      } keychange[3][14] = false;
    }
    if (keychange[3][13]) {
      if (kbrd[3][13]) {
        Keyboard.press('-');  // ;
      } else {
        Keyboard.release('-');
      } keychange[3][13] = false;
    }
    if (keychange[4][11]) {
      if (kbrd[4][11]) {
        Keyboard.press('4');  // u
      } else {
        Keyboard.release('4');
      } keychange[4][11] = false;
    }
    if (keychange[4][12]) {
      if (kbrd[4][12]) {
        Keyboard.press('5');  // i
      } else {
        Keyboard.release('5');
      } keychange[4][12] = false;
    }
    if (keychange[4][14]) {
      if (kbrd[4][14]) {
        Keyboard.press('6');  // o
      } else {
        Keyboard.release('6');
      } keychange[4][14] = false;
    }
    if (keychange[4][13]) {
      if (kbrd[4][13]) {
        Keyboard.press('*');  // p
      } else {
        Keyboard.release('*');
      } keychange[4][13] = false;
    }
    if (keychange[5][11]) {
      if (kbrd[5][11]) {
        Keyboard.press('7');  // 7
      } else {
        Keyboard.release('7');
      } keychange[5][11] = false;
    }
    if (keychange[5][12]) {
      if (kbrd[5][12]) {
        Keyboard.press('8');  // 8
      } else {
        Keyboard.release('8');
      } keychange[5][12] = false;
    }
    if (keychange[5][14]) {
      if (kbrd[5][14]) {
        Keyboard.press('9');  // 9
      } else {
        Keyboard.release('9');
      } keychange[5][14] = false;
    }
    if (keychange[5][13]) {
      if (kbrd[5][13]) {
        Keyboard.press('/');  // 0
      } else {
        Keyboard.release('/');
      } keychange[5][13] = false;
    }
*/    
  }

}


void transmit_keys() {

  int i, j;

  if (keychange[0][0]) {
    if (kbrd[0][0]) {
      Mouse.press(MOUSE_LEFT);
    } else {
      Mouse.release(MOUSE_LEFT);
    } keychange[0][0] = false;
  }
  if (keychange[0][15]) {
    if (kbrd[0][15]) {
      Mouse.press(MOUSE_MIDDLE);
    } else {
      Mouse.release(MOUSE_MIDDLE);
    } keychange[0][15] = false;
  }
  if (keychange[0][20]) {
    if (kbrd[0][20]) {
      Mouse.press(MOUSE_RIGHT);
    } else {
      Mouse.release(MOUSE_RIGHT);
    } keychange[0][20] = false;
  }

  for (i = 1; i < 9; i++) {
    for (j = 0; j < 21; j++) {
      if ((qwerty[i][j] != NULL) && keychange[i][j]) {
        keychange[i][j] = false;
        if (kbrd[i][j]) {
          Keyboard.press(qwerty[i][j]);
        } else {
          Keyboard.release(qwerty[i][j]);
        }
      }
    }
  }

}

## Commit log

2015-11-10 Schematic done. First commit.
    [laptop_kbrd.sch]
2015-11-11 Begun making new footprints.
    [laptop_kbrd.sch]
2015-11-11 Begun making new footprints. 3 left.
    [laptop_kbrd.kicad_pcb]
2015-11-14 All footprints done. Hopefully, FPC header has right parity.
    [laptop_kbrd.kicad_pcb]
2015-11-14 We'll need to do something about track clearances in PCB.
    [laptop_kbrd.kicad_pcb, laptop_kbrd.sch]
2015-11-17 Should I remove RCLAMP?
    [laptop_kbrd.kicad_pcb]
2015-11-17 Removed RCLAMP
    [laptop_kbrd.kicad_pcb, laptop_kbrd.sch]
2015-11-19 Added lidsense. Mounting holes.
    [laptop_kbrd.kicad_pcb, laptop_kbrd.sch]
2015-12-04 Modified pdf schematic.
2016-03-06 New components for the LCD controller.
    [laptop_kbrd.kicad_pcb, laptop_kbrd.sch]
2016-03-07 Gerbers left to be created.
    [laptop_kbrd.kicad_pcb, laptop_kbrd.sch]
2016-03-09 Fixed spin_half.lib issue, and removed sch file from gitignore.
    [LCD_board.sch]
2016-03-09 Added BOM csv file.
    [laptop_kbrd_BOM.csv]
2016-03-10 Changed internal Edge cuts to Silkscreen double lines for cutting with fret saw later. Generated and zipped Gerber files and drill file. Tested with Oshpark.
    [laptop_kbrd-B_Cu.gbl, laptop_kbrd-B_Mask.gbs, laptop_kbrd-B_Paste.gbp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]
2016-03-18 Modified footprint for 3pin_FPC connector (K1 and K2).
    [laptop_kbrd-B_Cu.gbl, laptop_kbrd-B_Mask.gbs, laptop_kbrd-B_Paste.gbp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]
2016-03-29 Added decals
    [laptop_kbrd-B_Cu.gbl, laptop_kbrd-B_Mask.gbs, laptop_kbrd-B_Paste.gbp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]
2016-04-30 First commit with license and readme file.
    [laptop_kbrd-B_Cu.gbl, laptop_kbrd-B_Mask.gbs, laptop_kbrd-B_Paste.gbp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]
2016-05-17 Changed TPM chip digikey part number to one that is available right now. 4x4 QFN packages are rare. Note to self: change layout to TSSOP in future version.
    [laptop_kbrd_BOM.csv]
2016-08-12 Swapped EPIT1_EPIT0 with GPT_CMPOUT3. Fixed usb d+ d- switch issue.
    [laptop_kbrd-B_Cu.gbl, laptop_kbrd-B_Mask.gbs, laptop_kbrd-B_Paste.gbp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]
2016-08-15 Added 5V breakout to kbrd panel. Changed BOM to reflect proper i2c (vs spi) encrypted eeprom chip. Made gerber files for kbrd only.
    [LCD_board.sch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]
2018-01-28 Adding LVDS 50 pin header to LCD front panel board. Also redoing reset pin for tusb2046b and crypto chip using RC circuit.
    [LCD_board.sch, laptop_kbrd.sch]
2018-01-31 New footprints in.
    [laptop_kbrd_BOM.csv]
2018-02-17 50 pin FFC cable now goes from motherboard to LCD board.
    [LCD_board.sch, LVDS_FFCcable.sch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]
2018-02-17 LCDbrdonly gerber folder created.
    [laptop_kbrd-B_Cu.gbl, laptop_kbrd-B_Mask.gbs, laptop_kbrd-B_Paste.gbp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]
2018-02-18 Minor changes. Moved some text to silkscren layer
    [laptop_kbrd-B_Cu.gbl, laptop_kbrd-B_Mask.gbs, laptop_kbrd-B_Paste.gbp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]
